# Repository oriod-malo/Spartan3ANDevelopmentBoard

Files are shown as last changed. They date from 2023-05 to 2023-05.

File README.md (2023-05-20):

# Spartan-3AN Development Board

## Description

A custom development board built over a Spartan-3AN FPGA. <br>
Built over 4 layers, it gives controlability over the Spartan-3AN Mode Pins through switches. This way it can be programmed both via JTAG and USB.
For the different combinations of Mode switches refer to Spartan-3AN documentation. For Slave Mode (where PIC32M250F128D acts as master), all three mode pins have to be HIGH.<br>
Note that the PIC32M250F128D requires adequate programming to function as the Master for the FPGA. 

## Features
* Spartan 3AN XC3S50AN-TQG144 FPGA
* PIC32MX250F128D-IPT for connecting with USB
* JTAG Header Pins
* M0-2 switches in order to switch from JTAG to Slave Mode to other modes and viceversa
* 4 Custom Switches
* 4 Pushbuttons
* 4 LED Lights
* VGA Connections
* All other pins connected with headers or sockets

## Images
Xilinx FPGA Board 3D
Xilinx FPGA Board Layers
Xilinx FPGA Board Layer 1
Xilinx FPGA Board Layer 2
Xilinx FPGA Board Layer 3
Xilinx FPGA Board Layer 4

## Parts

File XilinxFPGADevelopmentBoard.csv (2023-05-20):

Comment | Designator | Footprint | LCSC Part #
SW_Push_Dual Push button switch, generic, symbol, four pins | Button1,Button2,Button3,Button4 | SW_PUSH_6mm
100nF Unpolarized capacitor | C1,C2,C3,C4,C5,C6,C7,C8,C10,C11,C12,C13,C15,C16,C17,C18,C20,C21 | C_0201_0603Metric
1uF Unpolarized capacitor | C9,C14,C19,C28 | C_0201_0603Metric
10uF Unpolarized capacitor | C22 | C_0201_0603Metric
LED Light emitting diode | D1,D2,D3,D4 | LED_1206_3216Metric
LED Light emitting diode | D9 | LED_0201_0603Metric
Conn_02x07_Odd_Even Generic connector, double row, 02x07, odd/even pin numbering scheme (row 1 odd numbers, row 2 even numbers), script generated (kicad-library-utils/schlib/autogen/connector/) | J1 | IDC-Header_2x07_P2.54mm_Vertical
DE15_Receptacle_HighDensity 15-pin female receptacle socket D-SUB connector, High density (3 columns), Triple Row, Generic, VGA-connector | J2 | DSUB-15_Female_Horizontal_P2.77x2.84mm_EdgePinOffset14.56mm_Housed_MountingHolesOffset15.98mm
USB_B USB Type B connector | J3 | USB_B_Lumberg_2411_02_Horizontal
Conn_01x06 Generic connector, single row, 01x06, script generated (kicad-library-utils/schlib/autogen/connector/) | J4 | PinHeader_1x06_P2.54mm_Vertical
Conn_01x12 Generic connector, single row, 01x12, script generated (kicad-library-utils/schlib/autogen/connector/) | J5 | PinHeader_1x12_P2.54mm_Vertical
Conn_01x07_Socket Generic connector, single row, 01x07, script generated | J6 | PinSocket_1x07_P2.54mm_Vertical
Conn_01x10_Pin Generic connector, single row, 01x10, script generated | J7 | PinHeader_1x10_P2.54mm_Vertical
Conn_01x10_Socket Generic connector, single row, 01x10, script generated | J8 | PinSocket_1x10_P2.54mm_Vertical
Conn_01x13_Socket Generic connector, single row, 01x13, script generated | J9 | PinSocket_1x13_P2.54mm_Vertical
Conn_02x05_Odd_Even Generic connector, double row, 02x05, odd/even pin numbering scheme (row 1 odd numbers, row 2 even numbers), script generated (kicad-library-utils/schlib/autogen/connector/) | J10 | PinSocket_2x05_P2.54mm_Vertical
Conn_01x12_Pin Generic connector, single row, 01x12, script generated | J11 | PinHeader_1x12_P2.54mm_Vertical
Conn_02x09_Odd_Even Generic connector, double row, 02x09, odd/even pin numbering scheme (row 1 odd numbers, row 2 even numbers), script generated (kicad-library-utils/schlib/autogen/connector/) | J12 | PinSocket_2x09_P2.54mm_Vertical
470R Resistor | R1,R2,R3,R4 | R_1206_3216Metric
4.7k Resistor | R5,R6,R7,R20,R26,R28,R30 | R_0201_0603Metric
10k Resistor | R8,R9,R10,R11,R12,R13,R14,R25,R27,R29,R31 | R_0201_0603Metric
470R Resistor | R19 | R_0201_0603Metric
4k Resistor | RB0 | R_0201_0603Metric
2k Resistor | RB1 | R_0201_0603Metric
1k Resistor | RB2 | R_0201_0603Metric
510 Resistor | RB3 | R_0201_0603Metric
4k Resistor | RG0 | R_0201_0603Metric
2k Resistor | RG1 | R_0201_0603Metric
1k Resistor | RG2 | R_0201_0603Metric
510 Resistor | RG3 | R_0201_0603Metric
4k Resistor | RR0 | R_0201_0603Metric
2k Resistor | RR1 | R_0201_0603Metric
1k Resistor | RR2 | R_0201_0603Metric
510 Resistor | RR3 | R_0201_0603Metric
82.5R Resistor | RSYNC1,RSYNC2 | R_0201_0603Metric
0R Resistor | RZ1,RZ2,RZ3,RZ4 | R_0201_0603Metric
SW_SPDT Switch, single pole double throw | SW1,SW2,SW3,SW7,SW8,SW9,SW10 | SW_500SSP1S2M2QEA
XC3S50AN-TQG144 | U1 | QFP50P2200X2200X160-144N
PIC32MX250F128D-IPT 32-bit Microcontrollers (128KB Flash and 32KB SRAM TQFP-44) with Audio and Graphics Interfaces, USB, and Advanced Analog | U2 | TQFP-44_10x10mm_P0.8mm

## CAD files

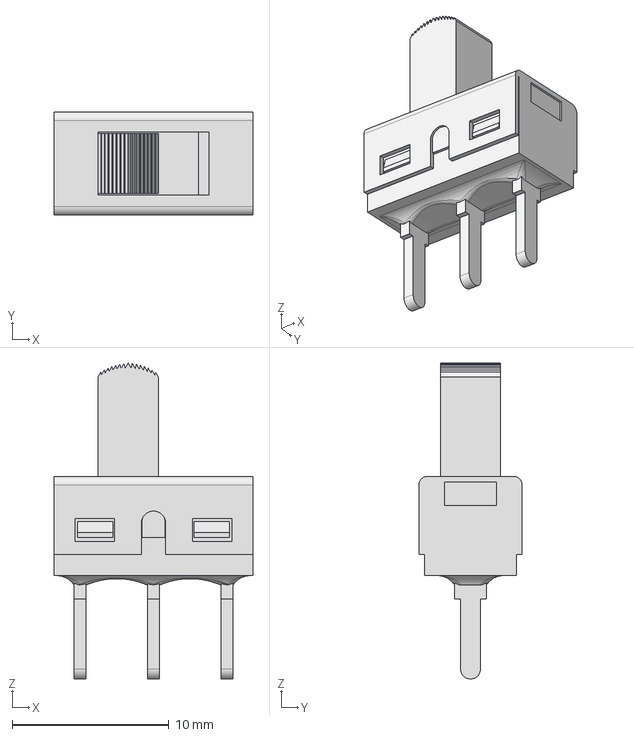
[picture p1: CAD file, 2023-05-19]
3dmodels/500SSP1S2M2QEA--3DModel-STEP-520916.STEP
12.7 x 6.60 x 20.2 mm

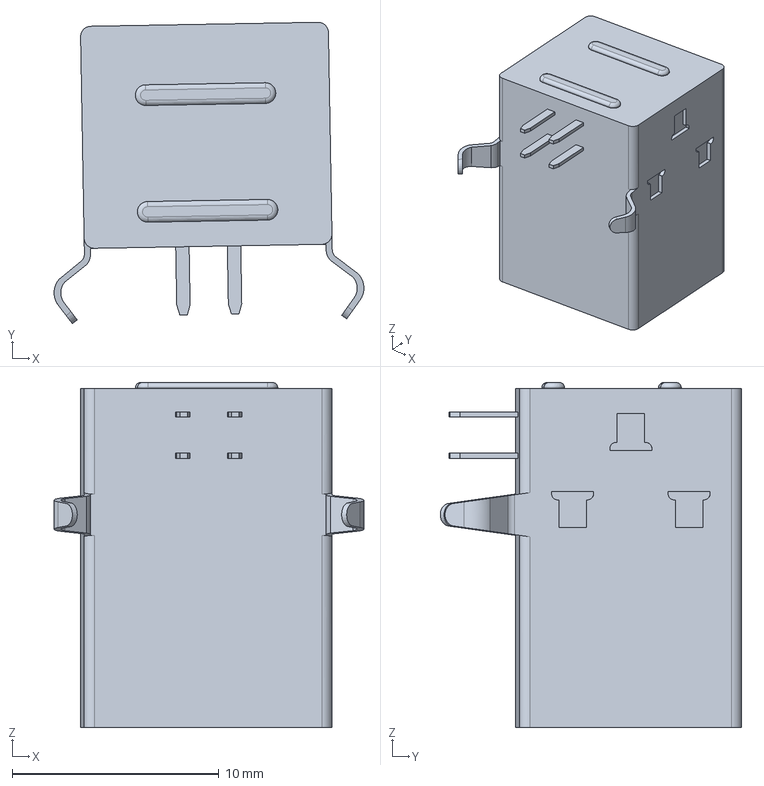
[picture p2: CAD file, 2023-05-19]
3dmodels/lumberg_2411_03.stp
15.0 x 14.6 x 16.7 mm

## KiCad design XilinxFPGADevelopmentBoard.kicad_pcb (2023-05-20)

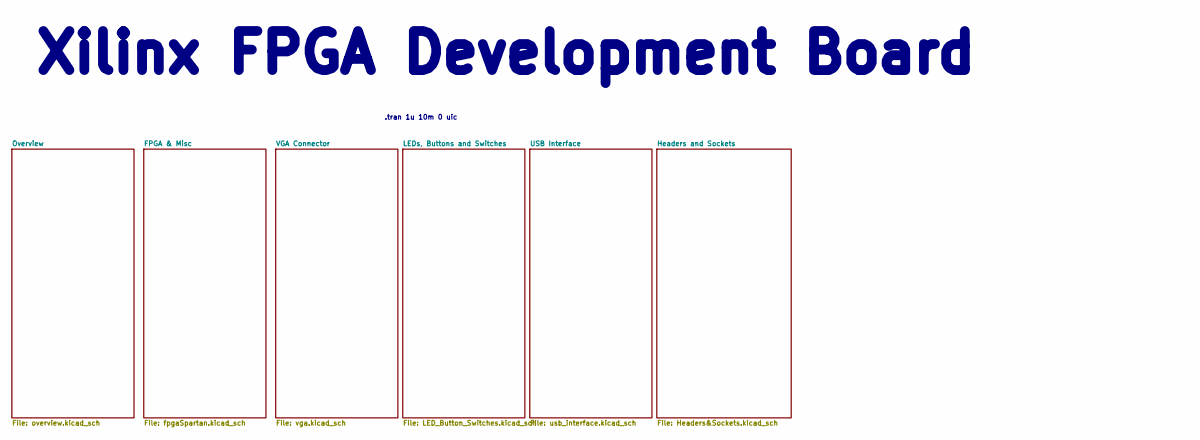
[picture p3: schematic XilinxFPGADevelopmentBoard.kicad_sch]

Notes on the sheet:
.tran 1u 10m 0 uic
Xilinx FPGA Development Board

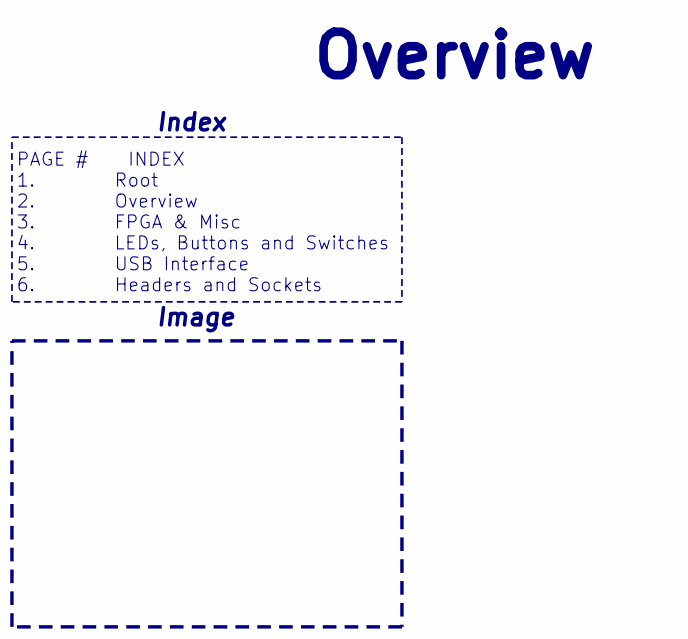
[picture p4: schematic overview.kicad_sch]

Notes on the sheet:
Image
Index
PAGE # INDEX 1. Root 2. Overview 3. FPGA & Misc 4. LEDs, Buttons and Switches 5. USB Interface 6. Headers and Sockets
Overview

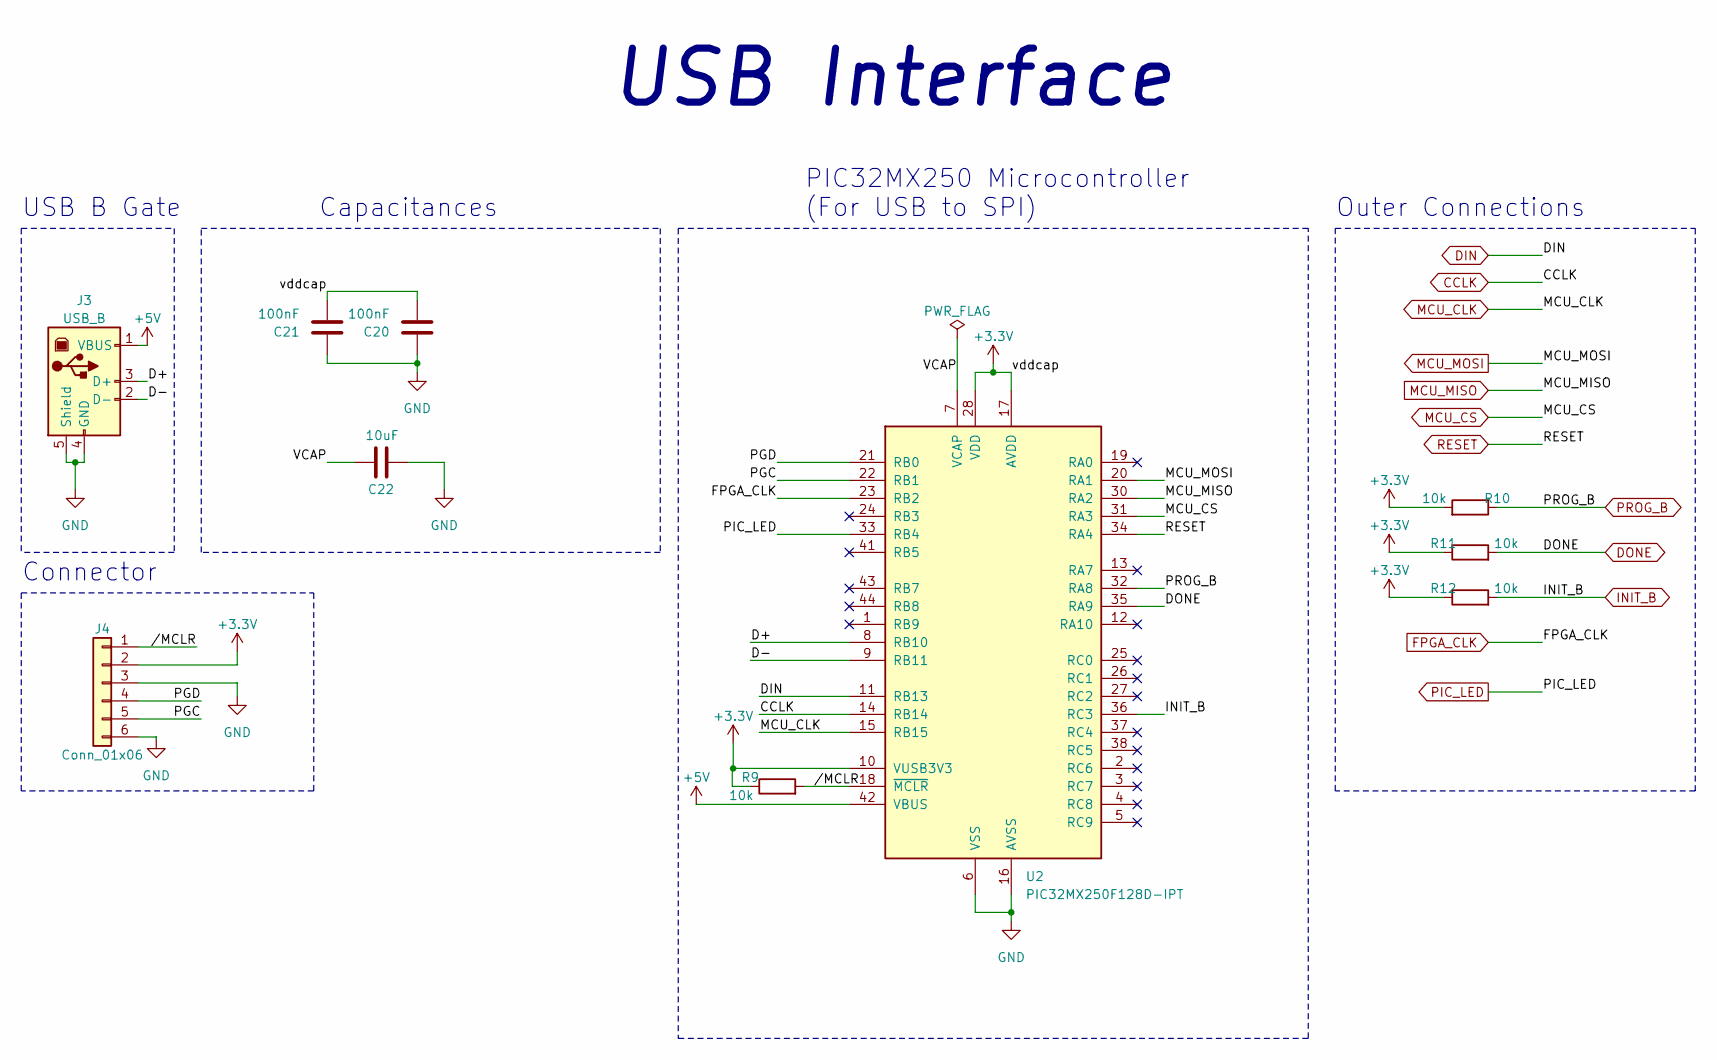
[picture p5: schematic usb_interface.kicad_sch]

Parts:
C20, C21: 100nF; C_0201_0603Metric
C22: 10uF; C_0201_0603Metric
J3: USB_B; USB_B_Lumberg_2411_02_Horizontal
J4: Conn_01x06; PinHeader_1x06_P2.54mm_Vertical
R9, R10, R11, R12: 10k; R_0201_0603Metric
U2: PIC32MX250F128D-IPT; TQFP-44_10x10mm_P0.8mm

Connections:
+3.3V: C20.2, C21.2, J4.2, R9.1, R10.2, R11.1, R12.1, U2.10 (VUSB3V3), U2.17 (AVDD), U2.28 (VDD), U2.40 (VDD); also elsewhere on the board
+5V: J3.1 (VBUS), U2.42 (VBUS)
/USB Interface/D+: J3.3 (D+), U2.8 (RB10)
/USB Interface/D-: J3.2 (D-), U2.9 (RB11)
/USB Interface/PGC: J4.5, U2.22 (RB1)
/USB Interface/PGD: J4.4, U2.21 (RB0)
/USB Interface/VCAP: C22.1, U2.7 (VCAP)
/USB Interface//MCLR: J4.1, R9.2, U2.18 (~MCLR)
CCLK: U2.14 (RB14); also elsewhere on the board
DIN: U2.11 (RB13); also elsewhere on the board
DONE: R11.2, U2.35 (RA9); also elsewhere on the board
FPGA_CLK: U2.23 (RB2); also elsewhere on the board
GND: C20.1, C21.1, C22.2, J3.4 (GND), J3.5 (Shield), J4.3, J4.6, U2.6 (VSS), U2.16 (AVSS), U2.29 (VSS), U2.39 (VSS); also elsewhere on the board
INIT_B: R12.2, U2.36 (RC3); also elsewhere on the board
MCU_CLK: U2.15 (RB15); also elsewhere on the board
MCU_CS: U2.31 (RA3); also elsewhere on the board
MCU_MISO: U2.30 (RA2); also elsewhere on the board
MCU_MOSI: U2.20 (RA1); also elsewhere on the board
PIC_LED: U2.33 (RB4); also elsewhere on the board
PROG_B: R10.1, U2.32 (RA8); also elsewhere on the board
RESET: U2.34 (RA4); also elsewhere on the board

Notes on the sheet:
Capacitances
USB Interface
Outer Connections
USB B Gate
PIC32MX250 Microcontroller (For USB to SPI)
Connector

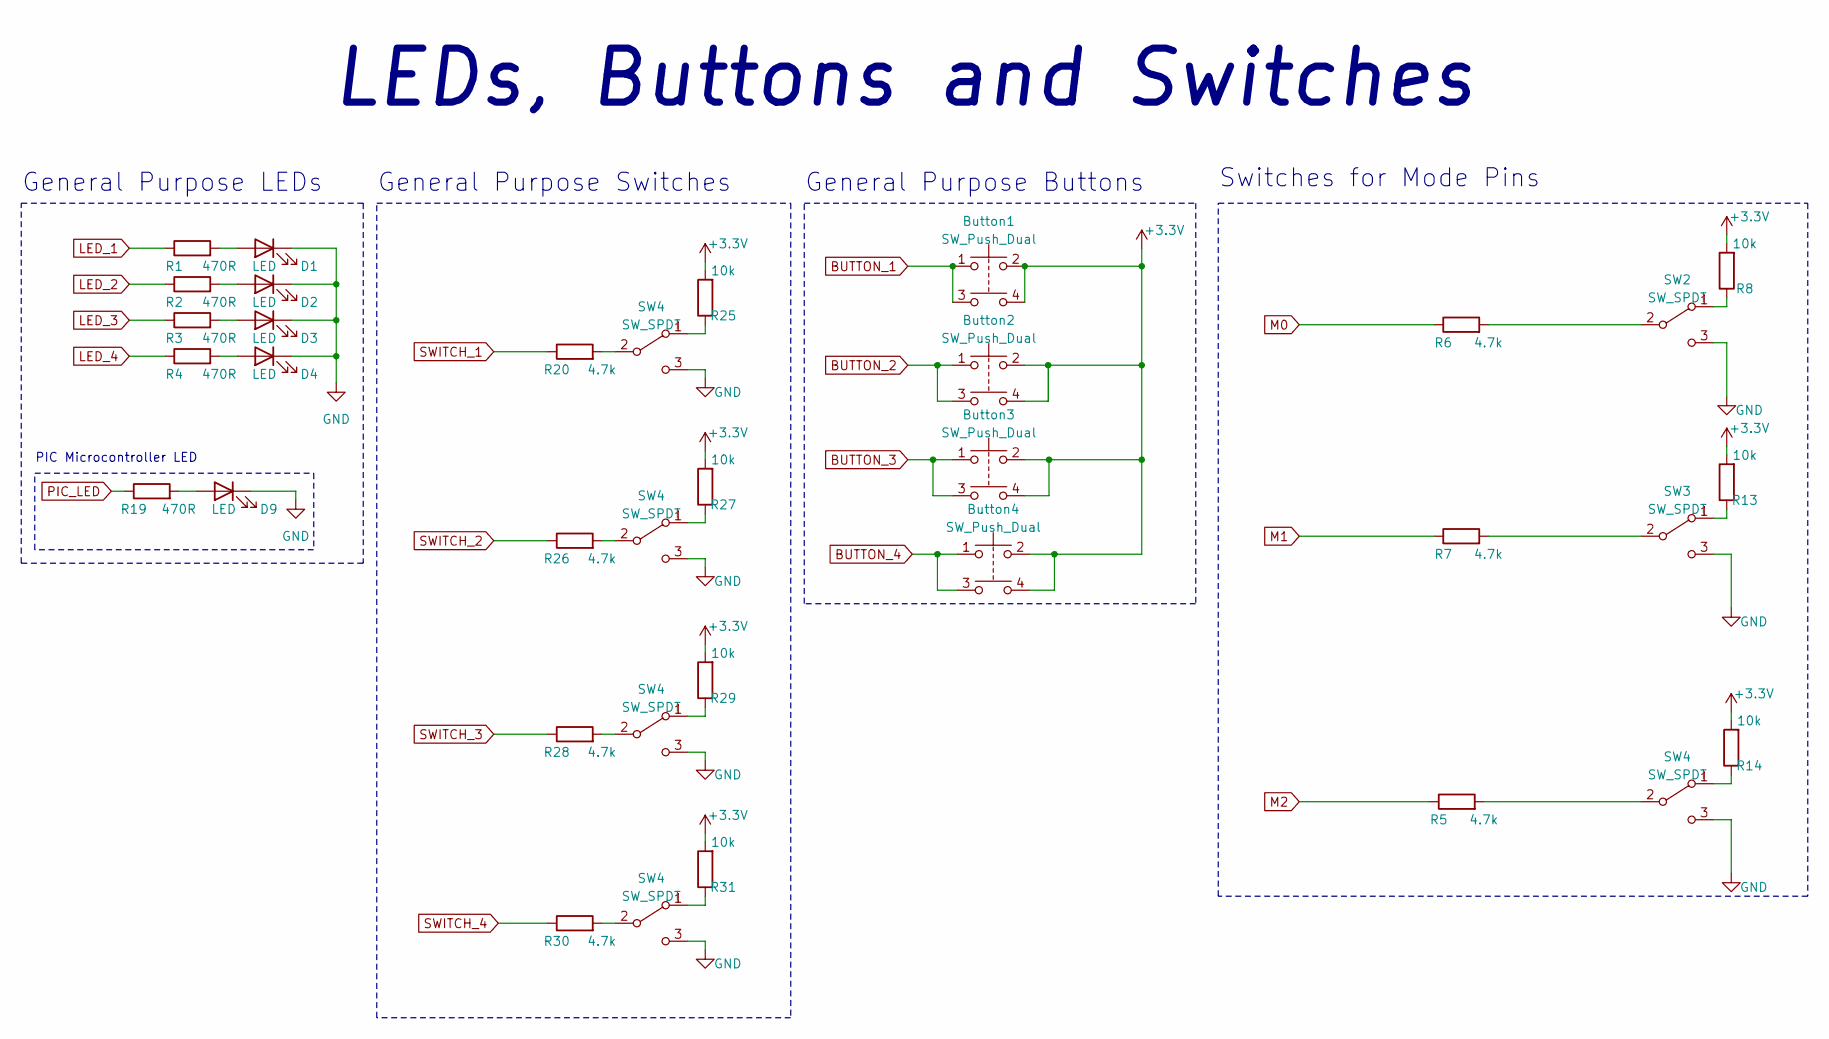
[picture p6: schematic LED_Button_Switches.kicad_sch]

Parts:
Button1, Button2, Button3, Button4: SW_Push_Dual; SW_PUSH_6mm
D1, D2, D3, D4: LED; LED_1206_3216Metric
D9: LED; LED_0201_0603Metric
R1, R2, R3, R4: 470R; R_1206_3216Metric
R5, R6, R7, R20, R26, R28, R30: 4.7k; R_0201_0603Metric
R8, R13, R14, R25, R27, R29, R31: 10k; R_0201_0603Metric
R19: 470R; R_0201_0603Metric
SW2, SW3, SW4: SW_SPDT; SW_500SSP1S2M2QEA

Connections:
+3.3V: Button1.2, Button1.4, Button2.2, Button2.4, Button3.2, Button3.4, Button4.2, Button4.4, R8.2, R13.2, R14.2, R25.2, R27.2, R29.2, R31.2; also elsewhere on the board
BUTTON_1: Button1.1, Button1.3; also elsewhere on the board
BUTTON_2: Button2.1, Button2.3; also elsewhere on the board
BUTTON_3: Button3.1, Button3.3; also elsewhere on the board
BUTTON_4: Button4.1, Button4.3; also elsewhere on the board
GND: D1.1 (K), D2.1 (K), D3.1 (K), D4.1 (K), D9.1 (K), SW2.3 (C), SW3.3 (C); also elsewhere on the board
LED_1: R1.1; also elsewhere on the board
LED_2: R2.1; also elsewhere on the board
LED_3: R3.1; also elsewhere on the board
LED_4: R4.1; also elsewhere on the board
M0: R6.1; also elsewhere on the board
M1: R7.1; also elsewhere on the board
M2: R5.1; also elsewhere on the board
unnamed: D1.2 (A), R1.2
unnamed: D2.2 (A), R2.2
unnamed: D3.2 (A), R3.2
unnamed: D4.2 (A), R4.2
unnamed: D9.2 (A), R19.2
unnamed 63: R25.1; also elsewhere on the board
unnamed 64: R20.2; also elsewhere on the board
unnamed 65: R27.1; also elsewhere on the board
unnamed 66: R26.2; also elsewhere on the board
unnamed 67: R29.1; also elsewhere on the board
unnamed 68: R28.2; also elsewhere on the board
unnamed 69: R31.1; also elsewhere on the board
unnamed 70: R30.2; also elsewhere on the board
PIC_LED: R19.1; also elsewhere on the board
SWITCH_1: R20.1; also elsewhere on the board
SWITCH_2: R26.1; also elsewhere on the board
SWITCH_3: R28.1; also elsewhere on the board
SWITCH_4: R30.1; also elsewhere on the board

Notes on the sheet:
General Purpose Buttons
PIC Microcontroller LED
LEDs, Buttons and Switches
General Purpose LEDs
Switches for Mode Pins
General Purpose Switches

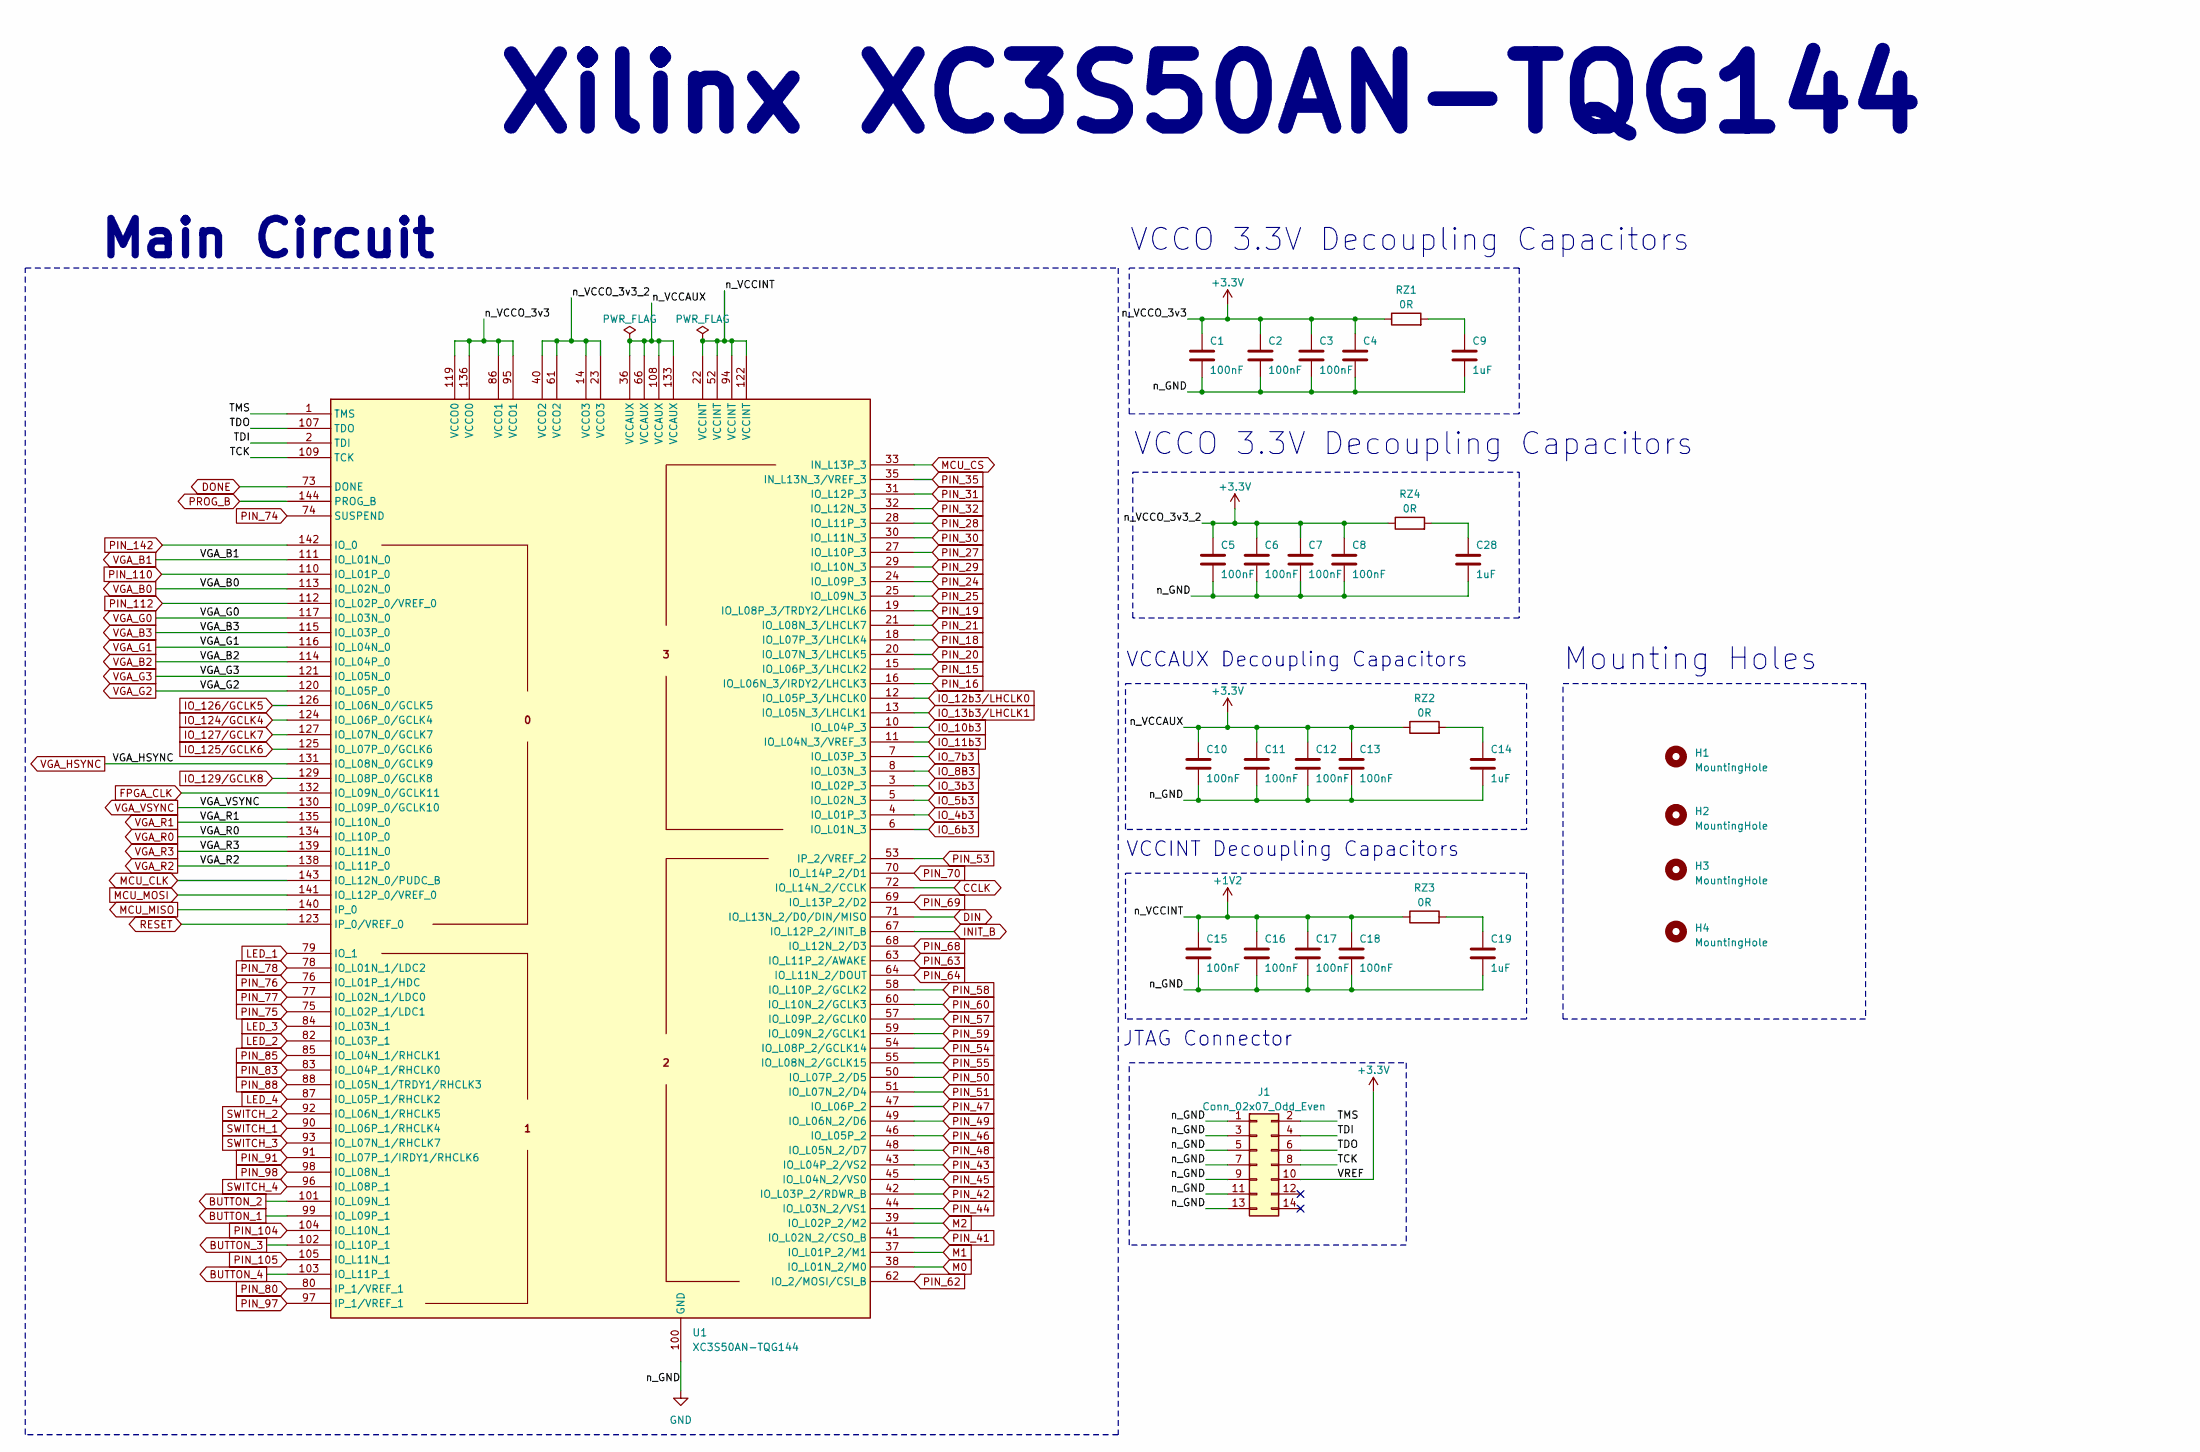
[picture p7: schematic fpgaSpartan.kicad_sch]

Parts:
C1, C2, C3, C4, C5, C6, C7, C8, C10, C11, C12, C13, C15, C16, C17, C18: 100nF; C_0201_0603Metric
C9, C14, C19, C28: 1uF; C_0201_0603Metric
H1, H2, H3, H4: MountingHole; MountingHole_2mm
J1: Conn_02x07_Odd_Even; IDC-Header_2x07_P2.54mm_Vertical
RZ1, RZ2, RZ3, RZ4: 0R; R_0201_0603Metric
U1: XC3S50AN-TQG144; QFP50P2200X2200X160-144N

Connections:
+1V2: C15.1, C16.1, C17.1, C18.1, RZ3.1, U1.22 (VCCINT), U1.52 (VCCINT), U1.94 (VCCINT), U1.122 (VCCINT)
+3.3V: C1.1, C2.1, C3.1, C4.1, C5.1, C6.1, C7.1, C8.1, C10.1, C11.1, C12.1, C13.1, J1.10, RZ1.1, RZ2.1, RZ4.1, U1.14 (VCCO3), U1.23 (VCCO3), U1.36 (VCCAUX), U1.40 (VCCO2), U1.61 (VCCO2), U1.66 (VCCAUX), U1.86 (VCCO1), U1.95 (VCCO1), U1.108 (VCCAUX), U1.119 (VCCO0), U1.133 (VCCAUX), U1.136 (VCCO0); also elsewhere on the board
/FPGA & Misc/TCK: J1.8, U1.109 (TCK)
/FPGA & Misc/TDI: J1.4, U1.2 (TDI)
/FPGA & Misc/TDO: J1.6, U1.107 (TDO)
/FPGA & Misc/TMS: J1.2, U1.1 (TMS)
BUTTON_1: U1.99 (IO_L09P_1); also elsewhere on the board
BUTTON_2: U1.101 (IO_L09N_1); also elsewhere on the board
BUTTON_3: U1.102 (IO_L10P_1); also elsewhere on the board
BUTTON_4: U1.103 (IO_L11P_1); also elsewhere on the board
CCLK: U1.72 (IO_L14N_2/CCLK); also elsewhere on the board
DIN: U1.71 (IO_L13N_2/D0/DIN/MISO); also elsewhere on the board
DONE: U1.73 (DONE); also elsewhere on the board
FPGA_CLK: U1.132 (IO_L09N_0/GCLK11); also elsewhere on the board
GND: C1.2, C2.2, C3.2, C4.2, C5.2, C6.2, C7.2, C8.2, C9.2, C10.2, C11.2, C12.2, C13.2, C14.2, C15.2, C16.2, C17.2, C18.2, C19.2, C28.2, J1.1, J1.3, J1.5, J1.7, J1.9, J1.11, J1.13, U1.9 (GND), U1.17 (GND), U1.26 (GND), U1.34 (GND), U1.56 (GND), U1.65 (GND), U1.81 (GND), U1.89 (GND), U1.100 (GND), U1.106 (GND), U1.118 (GND), U1.128 (GND), U1.137 (GND); also elsewhere on the board
INIT_B: U1.67 (IO_L12P_2/INIT_B); also elsewhere on the board
IO_3b3: U1.3 (IO_L02P_3); also elsewhere on the board
IO_4b3: U1.4 (IO_L01P_3); also elsewhere on the board
IO_5b3: U1.5 (IO_L02N_3); also elsewhere on the board
IO_6b3: U1.6 (IO_L01N_3); also elsewhere on the board
IO_7b3: U1.7 (IO_L03P_3); also elsewhere on the board
IO_8B3: U1.8 (IO_L03N_3); also elsewhere on the board
IO_10b3: U1.10 (IO_L04P_3); also elsewhere on the board
IO_11b3: U1.11 (IO_L04N_3/VREF_3); also elsewhere on the board
IO_12b3/LHCLK0: U1.12 (IO_L05P_3/LHCLK0); also elsewhere on the board
IO_13b3/LHCLK1: U1.13 (IO_L05N_3/LHCLK1); also elsewhere on the board
IO_124/GCLK4: U1.124 (IO_L06P_0/GCLK4); also elsewhere on the board
IO_125/GCLK6: U1.125 (IO_L07P_0/GCLK6); also elsewhere on the board
IO_126/GCLK5: U1.126 (IO_L06N_0/GCLK5); also elsewhere on the board
IO_127/GCLK7: U1.127 (IO_L07N_0/GCLK7); also elsewhere on the board
IO_129/GCLK8: U1.129 (IO_L08P_0/GCLK8); also elsewhere on the board
LED_1: U1.79 (IO_1); also elsewhere on the board
LED_2: U1.82 (IO_L03P_1); also elsewhere on the board
LED_3: U1.84 (IO_L03N_1); also elsewhere on the board
LED_4: U1.87 (IO_L05P_1/RHCLK2); also elsewhere on the board
M0: U1.38 (IO_L01N_2/M0); also elsewhere on the board
M1: U1.37 (IO_L01P_2/M1); also elsewhere on the board
M2: U1.39 (IO_L02P_2/M2); also elsewhere on the board
MCU_CLK: U1.143 (IO_L12N_0/PUDC_B); also elsewhere on the board
MCU_CS: U1.33 (IN_L13P_3); also elsewhere on the board
MCU_MISO: U1.140 (IP_0); also elsewhere on the board
MCU_MOSI: U1.141 (IO_L12P_0/VREF_0); also elsewhere on the board
unnamed: C9.1, RZ1.2
unnamed: C14.1, RZ2.2
unnamed: C19.1, RZ3.2
unnamed: C28.1, RZ4.2
PIN_15: U1.15 (IO_L06P_3/LHCLK2); also elsewhere on the board
PIN_16: U1.16 (IO_L06N_3/IRDY2/LHCLK3); also elsewhere on the board
PIN_18: U1.18 (IO_L07P_3/LHCLK4); also elsewhere on the board
PIN_19: U1.19 (IO_L08P_3/TRDY2/LHCLK6); also elsewhere on the board
PIN_20: U1.20 (IO_L07N_3/LHCLK5); also elsewhere on the board
PIN_21: U1.21 (IO_L08N_3/LHCLK7); also elsewhere on the board
PIN_24: U1.24 (IO_L09P_3); also elsewhere on the board
PIN_25: U1.25 (IO_L09N_3); also elsewhere on the board
PIN_27: U1.27 (IO_L10P_3); also elsewhere on the board
PIN_28: U1.28 (IO_L11P_3); also elsewhere on the board
PIN_29: U1.29 (IO_L10N_3); also elsewhere on the board
PIN_30: U1.30 (IO_L11N_3); also elsewhere on the board
PIN_31: U1.31 (IO_L12P_3); also elsewhere on the board
PIN_32: U1.32 (IO_L12N_3); also elsewhere on the board
PIN_35: U1.35 (IN_L13N_3/VREF_3); also elsewhere on the board
PIN_41: U1.41 (IO_L02N_2/CSO_B); also elsewhere on the board
PIN_42: U1.42 (IO_L03P_2/RDWR_B); also elsewhere on the board
PIN_43: U1.43 (IO_L04P_2/VS2); also elsewhere on the board
PIN_44: U1.44 (IO_L03N_2/VS1); also elsewhere on the board
PIN_45: U1.45 (IO_L04N_2/VS0); also elsewhere on the board
PIN_46: U1.46 (IO_L05P_2); also elsewhere on the board
PIN_47: U1.47 (IO_L06P_2); also elsewhere on the board
PIN_48: U1.48 (IO_L05N_2/D7); also elsewhere on the board
PIN_49: U1.49 (IO_L06N_2/D6); also elsewhere on the board
PIN_50: U1.50 (IO_L07P_2/D5); also elsewhere on the board
PIN_51: U1.51 (IO_L07N_2/D4); also elsewhere on the board
PIN_53: U1.53 (IP_2/VREF_2); also elsewhere on the board
PIN_54: U1.54 (IO_L08P_2/GCLK14); also elsewhere on the board
PIN_55: U1.55 (IO_L08N_2/GCLK15); also elsewhere on the board
PIN_57: U1.57 (IO_L09P_2/GCLK0); also elsewhere on the board
PIN_58: U1.58 (IO_L10P_2/GCLK2); also elsewhere on the board
PIN_59: U1.59 (IO_L09N_2/GCLK1); also elsewhere on the board
PIN_60: U1.60 (IO_L10N_2/GCLK3); also elsewhere on the board
PIN_62: U1.62 (IO_2/MOSI/CSI_B); also elsewhere on the board
PIN_63: U1.63 (IO_L11P_2/AWAKE); also elsewhere on the board
PIN_64: U1.64 (IO_L11N_2/DOUT); also elsewhere on the board
PIN_68: U1.68 (IO_L12N_2/D3); also elsewhere on the board
PIN_69: U1.69 (IO_L13P_2/D2); also elsewhere on the board
PIN_70: U1.70 (IO_L14P_2/D1); also elsewhere on the board
PIN_74: U1.74 (SUSPEND); also elsewhere on the board
PIN_75: U1.75 (IO_L02P_1/LDC1); also elsewhere on the board
PIN_76: U1.76 (IO_L01P_1/HDC); also elsewhere on the board
PIN_77: U1.77 (IO_L02N_1/LDC0); also elsewhere on the board
PIN_78: U1.78 (IO_L01N_1/LDC2); also elsewhere on the board
PIN_80: U1.80 (IP_1/VREF_1); also elsewhere on the board
PIN_83: U1.83 (IO_L04P_1/RHCLK0); also elsewhere on the board
PIN_85: U1.85 (IO_L04N_1/RHCLK1); also elsewhere on the board
PIN_88: U1.88 (IO_L05N_1/TRDY1/RHCLK3); also elsewhere on the board
PIN_91: U1.91 (IO_L07P_1/IRDY1/RHCLK6); also elsewhere on the board
PIN_97: U1.97 (IP_1/VREF_1); also elsewhere on the board
PIN_98: U1.98 (IO_L08N_1); also elsewhere on the board
PIN_104: U1.104 (IO_L10N_1); also elsewhere on the board
PIN_105: U1.105 (IO_L11N_1); also elsewhere on the board
PIN_110: U1.110 (IO_L01P_0); also elsewhere on the board
PIN_112: U1.112 (IO_L02P_0/VREF_0); also elsewhere on the board
PIN_142: U1.142 (IO_0); also elsewhere on the board
PROG_B: U1.144 (PROG_B); also elsewhere on the board
RESET: U1.123 (IP_0/VREF_0); also elsewhere on the board
SWITCH_1: U1.90 (IO_L06P_1/RHCLK4); also elsewhere on the board
SWITCH_2: U1.92 (IO_L06N_1/RHCLK5); also elsewhere on the board
SWITCH_3: U1.93 (IO_L07N_1/RHCLK7); also elsewhere on the board
SWITCH_4: U1.96 (IO_L08P_1); also elsewhere on the board
VGA_B0: U1.113 (IO_L02N_0); also elsewhere on the board
VGA_B1: U1.111 (IO_L01N_0); also elsewhere on the board
VGA_B2: U1.114 (IO_L04P_0); also elsewhere on the board
VGA_B3: U1.115 (IO_L03P_0); also elsewhere on the board
VGA_G0: U1.117 (IO_L03N_0); also elsewhere on the board
VGA_G1: U1.116 (IO_L04N_0); also elsewhere on the board
VGA_G2: U1.120 (IO_L05P_0); also elsewhere on the board
VGA_G3: U1.121 (IO_L05N_0); also elsewhere on the board
VGA_HSYNC: U1.131 (IO_L08N_0/GCLK9); also elsewhere on the board
VGA_R0: U1.134 (IO_L10P_0); also elsewhere on the board
VGA_R1: U1.135 (IO_L10N_0); also elsewhere on the board
VGA_R2: U1.138 (IO_L11P_0); also elsewhere on the board
VGA_R3: U1.139 (IO_L11N_0); also elsewhere on the board
VGA_VSYNC: U1.130 (IO_L09P_0/GCLK10); also elsewhere on the board

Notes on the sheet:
JTAG Connector
Mounting Holes
VCCAUX Decoupling Capacitors
VCCO 3.3V Decoupling Capacitors
Xilinx XC3S50AN-TQG144
VCCINT Decoupling Capacitors
Main Circuit

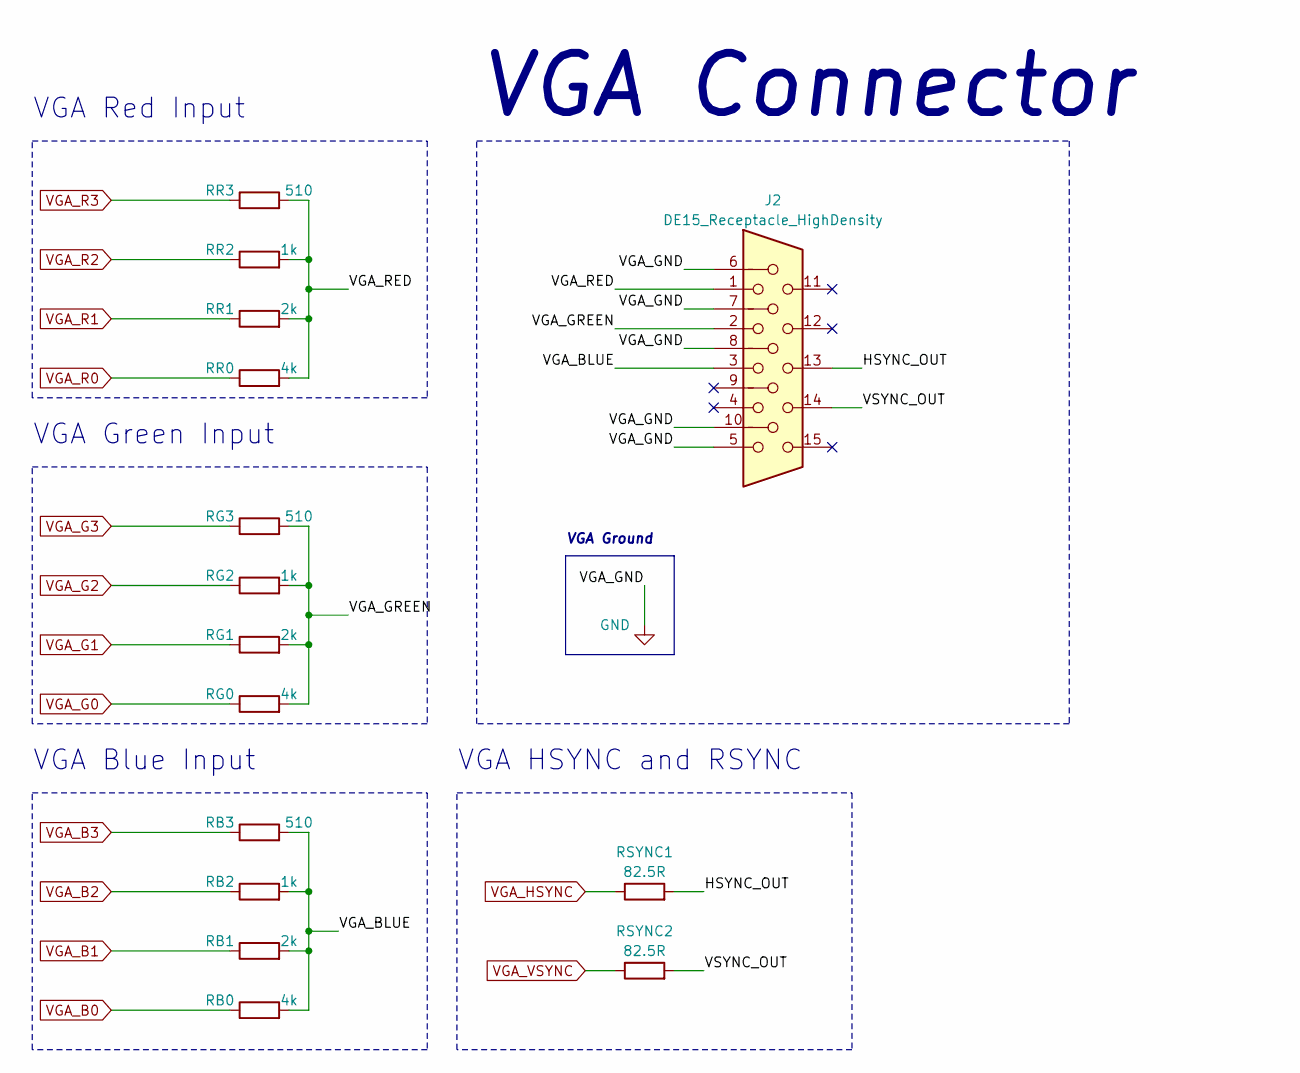
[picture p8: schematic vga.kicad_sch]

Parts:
J2: DE15_Receptacle_HighDensity; DSUB-15_Female_Horizontal_P2.77x2.84mm_EdgePinOffset14.56mm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
RB0: 4k; R_0201_0603Metric
RB1: 2k; R_0201_0603Metric
RB2: 1k; R_0201_0603Metric
RB3: 510; R_0201_0603Metric
RG0: 4k; R_0201_0603Metric
RG1: 2k; R_0201_0603Metric
RG2: 1k; R_0201_0603Metric
RG3: 510; R_0201_0603Metric
RR0: 4k; R_0201_0603Metric
RR1: 2k; R_0201_0603Metric
RR2: 1k; R_0201_0603Metric
RR3: 510; R_0201_0603Metric
RSYNC1, RSYNC2: 82.5R; R_0201_0603Metric

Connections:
/VGA Connector/HSYNC_OUT: J2.13, RSYNC1.2
/VGA Connector/VGA_BLUE: J2.3, RB0.2, RB1.2, RB2.2, RB3.2
/VGA Connector/VGA_GREEN: J2.2, RG0.2, RG1.2, RG2.2, RG3.2
/VGA Connector/VGA_RED: J2.1, RR0.2, RR1.2, RR2.2, RR3.2
/VGA Connector/VSYNC_OUT: J2.14, RSYNC2.2
GND: J2.5, J2.6, J2.7, J2.8, J2.10; also elsewhere on the board
VGA_B0: RB0.1; also elsewhere on the board
VGA_B1: RB1.1; also elsewhere on the board
VGA_B2: RB2.1; also elsewhere on the board
VGA_B3: RB3.1; also elsewhere on the board
VGA_G0: RG0.1; also elsewhere on the board
VGA_G1: RG1.1; also elsewhere on the board
VGA_G2: RG2.1; also elsewhere on the board
VGA_G3: RG3.1; also elsewhere on the board
VGA_HSYNC: RSYNC1.1; also elsewhere on the board
VGA_R0: RR0.1; also elsewhere on the board
VGA_R1: RR1.1; also elsewhere on the board
VGA_R2: RR2.1; also elsewhere on the board
VGA_R3: RR3.1; also elsewhere on the board
VGA_VSYNC: RSYNC2.1; also elsewhere on the board

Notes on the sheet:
VGA Green Input
VGA Blue Input
VGA Red Input
VGA Connector
VGA Ground
VGA HSYNC and RSYNC

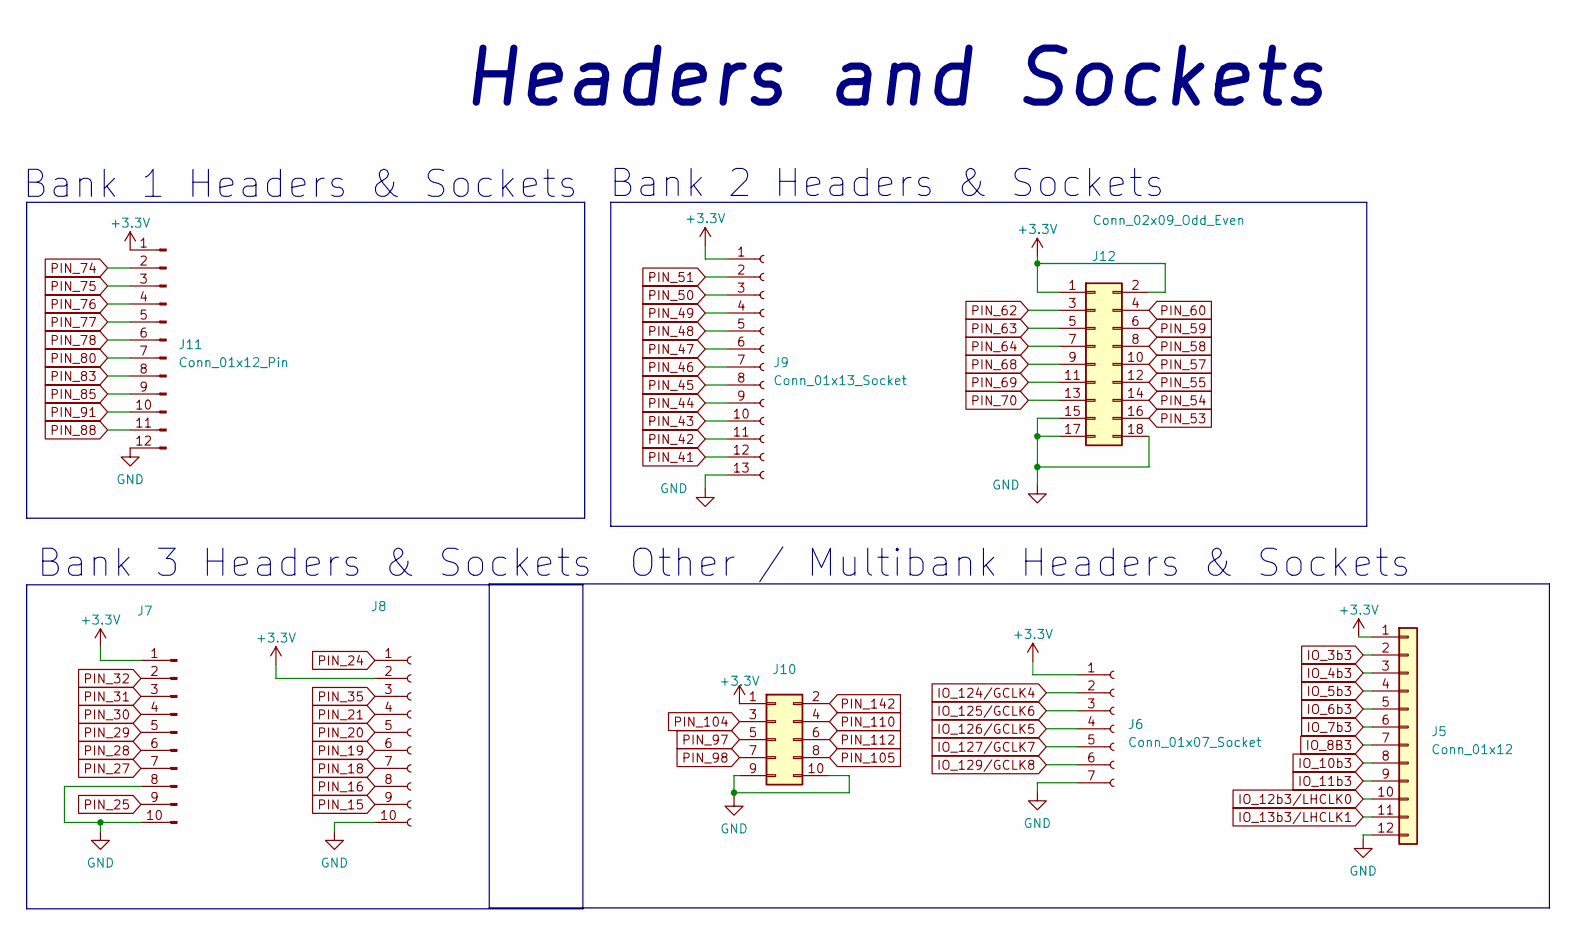
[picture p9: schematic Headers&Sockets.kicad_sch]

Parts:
J5: Conn_01x12; PinHeader_1x12_P2.54mm_Vertical
J6: Conn_01x07_Socket; PinSocket_1x07_P2.54mm_Vertical
J7: Conn_01x10_Pin; PinHeader_1x10_P2.54mm_Vertical
J8: Conn_01x10_Socket; PinSocket_1x10_P2.54mm_Vertical
J9: Conn_01x13_Socket; PinSocket_1x13_P2.54mm_Vertical
J10: Conn_02x05_Odd_Even; PinSocket_2x05_P2.54mm_Vertical
J11: Conn_01x12_Pin; PinHeader_1x12_P2.54mm_Vertical
J12: Conn_02x09_Odd_Even; PinSocket_2x09_P2.54mm_Vertical

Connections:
+3.3V: J5.1, J6.1, J7.1, J8.2, J9.1, J10.1, J11.1, J12.1, J12.2; also elsewhere on the board
GND: J5.12, J6.7, J7.8, J7.10, J8.10, J9.13, J10.9, J10.10, J11.12, J12.15, J12.17, J12.18; also elsewhere on the board
IO_3b3: J5.2; also elsewhere on the board
IO_4b3: J5.3; also elsewhere on the board
IO_5b3: J5.4; also elsewhere on the board
IO_6b3: J5.5; also elsewhere on the board
IO_7b3: J5.6; also elsewhere on the board
IO_8B3: J5.7; also elsewhere on the board
IO_10b3: J5.8; also elsewhere on the board
IO_11b3: J5.9; also elsewhere on the board
IO_12b3/LHCLK0: J5.10; also elsewhere on the board
IO_13b3/LHCLK1: J5.11; also elsewhere on the board
IO_124/GCLK4: J6.2; also elsewhere on the board
IO_125/GCLK6: J6.3; also elsewhere on the board
IO_126/GCLK5: J6.4; also elsewhere on the board
IO_127/GCLK7: J6.5; also elsewhere on the board
IO_129/GCLK8: J6.6; also elsewhere on the board
PIN_15: J8.9; also elsewhere on the board
PIN_16: J8.8; also elsewhere on the board
PIN_18: J8.7; also elsewhere on the board
PIN_19: J8.6; also elsewhere on the board
PIN_20: J8.5; also elsewhere on the board
PIN_21: J8.4; also elsewhere on the board
PIN_24: J8.1; also elsewhere on the board
PIN_25: J7.9; also elsewhere on the board
PIN_27: J7.7; also elsewhere on the board
PIN_28: J7.6; also elsewhere on the board
PIN_29: J7.5; also elsewhere on the board
PIN_30: J7.4; also elsewhere on the board
PIN_31: J7.3; also elsewhere on the board
PIN_32: J7.2; also elsewhere on the board
PIN_35: J8.3; also elsewhere on the board
PIN_41: J9.12; also elsewhere on the board
PIN_42: J9.11; also elsewhere on the board
PIN_43: J9.10; also elsewhere on the board
PIN_44: J9.9; also elsewhere on the board
PIN_45: J9.8; also elsewhere on the board
PIN_46: J9.7; also elsewhere on the board
PIN_47: J9.6; also elsewhere on the board
PIN_48: J9.5; also elsewhere on the board
PIN_49: J9.4; also elsewhere on the board
PIN_50: J9.3; also elsewhere on the board
PIN_51: J9.2; also elsewhere on the board
PIN_53: J12.16; also elsewhere on the board
PIN_54: J12.14; also elsewhere on the board
PIN_55: J12.12; also elsewhere on the board
PIN_57: J12.10; also elsewhere on the board
PIN_58: J12.8; also elsewhere on the board
PIN_59: J12.6; also elsewhere on the board
PIN_60: J12.4; also elsewhere on the board
PIN_62: J12.3; also elsewhere on the board
PIN_63: J12.5; also elsewhere on the board
PIN_64: J12.7; also elsewhere on the board
PIN_68: J12.9; also elsewhere on the board
PIN_69: J12.11; also elsewhere on the board
PIN_70: J12.13; also elsewhere on the board
PIN_74: J11.2; also elsewhere on the board
PIN_75: J11.3; also elsewhere on the board
PIN_76: J11.4; also elsewhere on the board
PIN_77: J11.5; also elsewhere on the board
PIN_78: J11.6; also elsewhere on the board
PIN_80: J11.7; also elsewhere on the board
PIN_83: J11.8; also elsewhere on the board
PIN_85: J11.9; also elsewhere on the board
PIN_88: J11.11; also elsewhere on the board
PIN_91: J11.10; also elsewhere on the board
PIN_97: J10.5; also elsewhere on the board
PIN_98: J10.7; also elsewhere on the board
PIN_104: J10.3; also elsewhere on the board
PIN_105: J10.8; also elsewhere on the board
PIN_110: J10.4; also elsewhere on the board
PIN_112: J10.6; also elsewhere on the board
PIN_142: J10.2; also elsewhere on the board

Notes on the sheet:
Bank 1 Headers & Sockets
Headers and Sockets
Other / Multibank Headers & Sockets
Bank 3 Headers & Sockets
Bank 2 Headers & Sockets

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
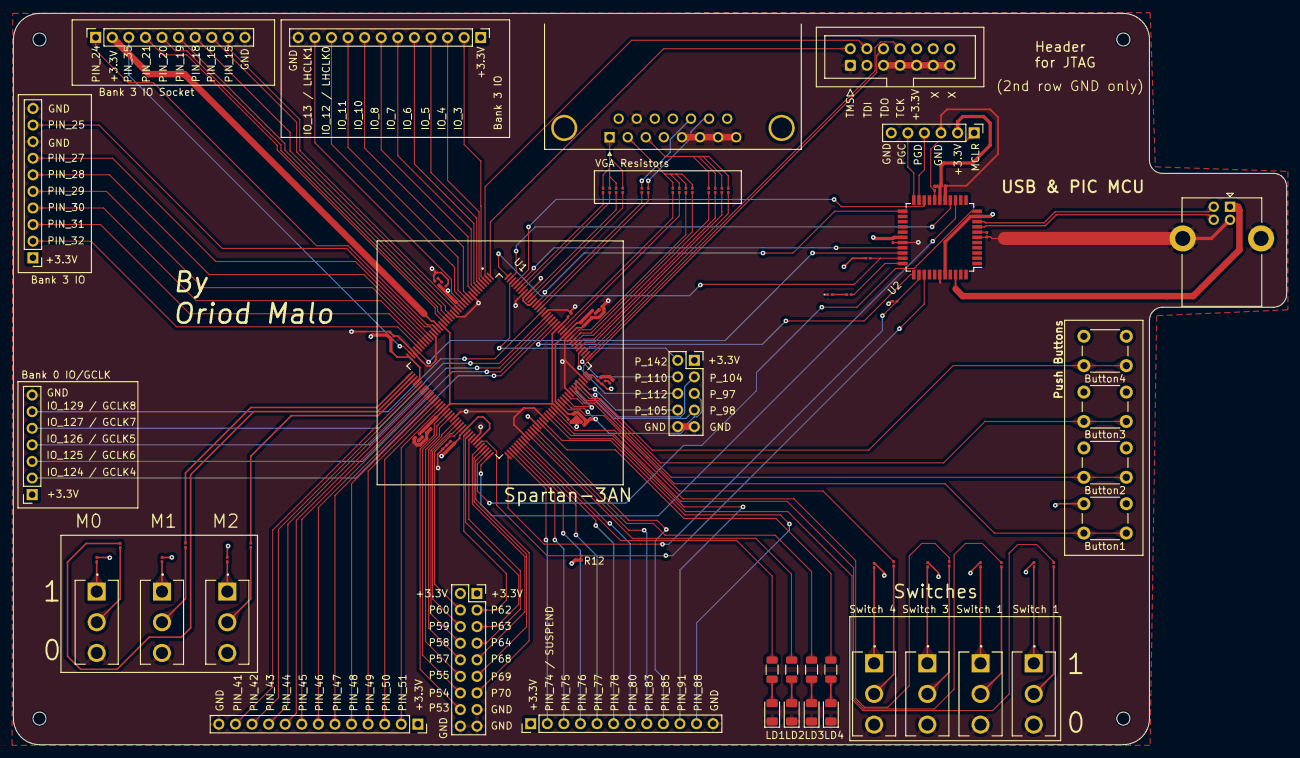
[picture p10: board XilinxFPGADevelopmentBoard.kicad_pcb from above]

Board: 4 copper layers, 195.0 x 112.0 mm, 98 parts (0 on the bottom side), 154 nets.

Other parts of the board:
SW1, SW7, SW8, SW9, SW10: SW_SPDT; SW_500SSP1S2M2QEA

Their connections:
GND: SW1.3 (C), SW7.3 (C), SW8.3 (C), SW9.3 (C), SW10.3 (C); also elsewhere on the board
unnamed 63: SW7.1 (A); also elsewhere on the board
unnamed 64: SW7.2 (B); also elsewhere on the board
unnamed 65: SW8.1 (A); also elsewhere on the board
unnamed 66: SW8.2 (B); also elsewhere on the board
unnamed 67: SW9.1 (A); also elsewhere on the board
unnamed 68: SW9.2 (B); also elsewhere on the board
unnamed 69: SW10.1 (A); also elsewhere on the board
unnamed 70: SW10.2 (B); also elsewhere on the board
